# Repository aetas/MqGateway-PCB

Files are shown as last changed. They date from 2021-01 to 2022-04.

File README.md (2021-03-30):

# MqGateway PCB projects

Schematics and PCB design for MqGateway boards.

Source files can be read with [KiCad](https://kicad-pcb.org/). GERBER files are available in the [releases](https://github.com/aetas/MqGateway-PCB/releases).

Read more about MqGateway on the [documentation site](https://mqgateway.com).

## Issues

If you have found any problem with the PCB projects - please create an issue in [aetas/mqgateway repository](https://github.com/aetas/mqgateway).

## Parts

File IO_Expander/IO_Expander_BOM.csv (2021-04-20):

Quantity | Value | References | Package | Device | Description | Link
4 | Screw_Terminal_01x02 | 12V_OUTPUT_1, 5V_OUTPUT_1, EXT_BUTTON_1, POWER_SWITCH_1 |  |  | Screw Terminal 2-pin | https://www.piekarz.pl/00561-laczowka-xy306a-02p-5-0mm-2-tory/
1 | Power switch | POWER_SWITCH_1 |  | KCD1-110A | Sub-miniature Rocker Switch OFF-ON, power switch | https://en.maritex.com.pl/product/show/39905
1 | LED Red 3mm | 12V_POWER_LED_1 | d=3mm |  | Red LED d=3mm
1 |  | R_12V_POWER_LED_1 | THT |  | Red LED resistor
1 | LED Red 3mm | 5V_POWER_LED_1 | d=3mm |  | Red LED d=3mm
1 |  | R_5V_POWER_LED_1 | THT |  | Red LED resistor
1 | LED Blue 3mm | EXTENDER_CHECK_LED_1 | d=3mm |  | Blue LED d=3mm
1 |  | R_EXTENDER_CHECK_LED_1 | THT |  | Blue LED resistor
1 |  | DC_JACK_1 |  |  | DC Power Jack Plug Socket 2.1/5.5 | https://www.piekarz.pl/02542-gniazdo-zasilajace-dc-gdc21-55-2-1mm/
4 |  | EXPANDER_1, EXPANDER_2, EXPANDER_3, EXPANDER_4 | DIP28 | MCP23017-E/SP | MCP23017 expanders | https://www.piekarz.pl/22712-przetwornik-microchip-mcp23017-e-sp/
4 | 36x10mm | EXPANDER_1, EXPANDER_2, EXPANDER_3, EXPANDER_4 | DIP28p narrow (0.3'') |  | DIP28 sockets for MCP23017 expanders | https://www.piekarz.pl/04818-podstawka-zwykla-dip-dip28p-28-torow/
1 |  | LM2596_Module_1 |  | LM2596 module | LM2596 Step-Down module | https://www.aliexpress.com/item/4000627309533.html
1 | 8P8C x16 | RJ45x16_1 |  | RJ45 x16 | 8P8C/RJ45 Ethernet Socket 2x8 Ports | https://www.aliexpress.com/item/1212644854.html
1 |  | RS485_CONNECTOR_1 |  | PTR STL1550/4G-3.5-H | Terminal block 4-pins 3.5mm | https://www.piekarz.pl/00604-laczowka-stl1550-4-gh-4-tory/
1 | 2x2 | RS485_OUT_Jumpers_1 |  |  | Pin header 2x2 | https://www.piekarz.pl/35904-piny-wtyk-pld20s-20-torow/
2 | Jumper | RS485_OUT_Jumpers_1 |  |  | Jumper for pin header | https://www.piekarz.pl/00481-zwora-jumper-b-1-tor/
3 | Jumper | SW_SLIDE_SPDT_1, SW_SLIDE_SPDT_2, SW_SLIDE_SPDT_3 |  | KLS7-SS02-12F20 | Miniature SPDT Slide Switch ON-ON | https://www.piekarz.pl/33509-przelacznik-ss02-12f20-l-6/
2 |  | EXTRA_IO_CONNECTOR_1, EXTRA_IO_CONNECTOR_2 |  |  | IDC 10 pin male socket | https://www.piekarz.pl/17934-wtyk-bh10-s-10-torow/
2 | IDC10-CT | - |  |  | Female IDC-plug 10 pin for ribbon cable | https://www.piekarz.pl/02212-gniazdo-fc10-idc10-10-torow/
1 | 10-core ribbon | - |  |  | 10-core ribbon cable | https://www.piekarz.pl/06502-przewod-plaski-awg28-10-10-zyl-linka-cu-0-09mm2/

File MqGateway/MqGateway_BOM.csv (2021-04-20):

Quantity | Value | References | Package | Device | Description | Link
4 | 2x2 | 3V3_ADD_1, 5V_ADD_1, RS485_MAX_Jumpers_1, RS485_Jumpers_1 |  |  | Pin header 2x2 | https://www.piekarz.pl/35904-piny-wtyk-pld20s-20-torow/
1 | 1x2 | 5V_TO_DL33CV_JUMPER_1 |  |  | Pin header 1x2 | https://www.piekarz.pl/35901-piny-wtyk-pls02s-2-tory/
5 | Jumper | 3V3_ADD_1, 5V_ADD_1, RS485_MAX_Jumpers_1, RS485_Jumpers_1, 5V_TO_DL33CV_JUMPER_1 |  |  | Jumper for pin header | https://www.piekarz.pl/00481-zwora-jumper-b-1-tor/
1 | LD1117V33 | 3V3_REGULATOR_1 | TO-220-3 | LD1117V33 | Linear Voltage Regulator 3.3V | https://www.piekarz.pl/13101-stabilizator-st-microelectronics-ld1117v33c/
2 | SW_Push | BUTTON_1 BUTTON_2 |  | KLS7-TS6601 | Tact switch button 4-pin (6x6mm) | https://www.piekarz.pl/00678-mikroprzycisk-kls-ts6601-5-6x6mm-5mm-1-5mm/
2 | Screw_Terminal_01x02 | POWER_SWITCH_1, BUTTON_3 |  |  | Screw Terminal 2-pin | https://www.piekarz.pl/00561-laczowka-xy306a-02p-5-0mm-2-tory/
1 | DC 5V | DC_JACK_1 |  |  | DC Power Jack Plug Socket 2.1/5.5 | https://www.piekarz.pl/02542-gniazdo-zasilajace-dc-gdc21-55-2-1mm/
4 | MCP23017-E/SP | EXPANDER_1, EXPANDER_2, EXPANDER_3, EXPANDER_4 | DIP28 | MCP23017-E/SP | MCP23017 expanders | https://www.piekarz.pl/22712-przetwornik-microchip-mcp23017-e-sp/
4 | 36x10mm | EXPANDER_1, EXPANDER_2, EXPANDER_3, EXPANDER_4 | DIP28p narrow (0.3'') |  | DIP28 sockets for MCP23017 expanders | https://www.piekarz.pl/04818-podstawka-zwykla-dip-dip28p-28-torow/
1 | Extra IO Connector | EXTRA_IO_CONNECTOR_1 |  |  | Extra IO Connector, IDC 10 pin male socket | https://www.piekarz.pl/17934-wtyk-bh10-s-10-torow/
1 | LEVEL SHIFTER | LEVEL_SHIFTER_1 |  |  | Logic level converter 4-ch 5V to 3.3V | https://www.aliexpress.com/item/32715353192.html
1 | MAX485 | MAX485 |  |  | MAX485 TTL to RS-485 Interface Module | https://www.aliexpress.com/item/4000112077167.html
1 | 2x12 | NanoPi_NEO_1 |  |  | NanoPi NEO Socket, IDC 24 pin male socket | https://www.maritex.com.pl/zlacza/zlacza_idc/idc_w_rastrze_2_54mm/zlacza_kolkowe_proste_w_rastrze_2_54mm_conntherm_1/bh24s-ct.html
4 | M2.5 30mm | - |  | WKKM2530 | Screw M2.5 30mm for NanoPi NEO | https://www.piekarz.pl/21920-wkret-m2-5-wkkm2530/
4 | M2.5 | - |  | NOM252 | Screw Nut M2.5 for NanoPi NEO | https://www.piekarz.pl/09575-nakretka-m2-5-nom252/
2 | IDC24-CT | - |  | IDC24-CT | Female IDC-plug 24 pin for ribbon cable | https://en.maritex.com.pl/connectors/idc_connectors/idc_connectors_2_54mm_pitch/idc_female_sockets_for_ribbon_cable_2_54_mm_pitch_conntherm/idc24-ct.html
1 | 15cm 24-core ribbon | - |  |  | 24-core ribbon cable (15cm) | https://www.aliexpress.com/item/32824377459.html
1 | LED Red 3mm | POWER_LED_1 | THT d=3mm |  | Red LED d=3mm
1 | 150 | R_LED_POWER_1 | THT |  | Red LED resistor
1 | 8P8C x16 | RJ45x16_1 |  |  | 8P8C/RJ45 Ethernet Socket 2x8 Ports | https://www.aliexpress.com/item/1212644854.html
1 | LED Yellow Green 3mm | STATUS_RGB_LED_1 | THT d=3mm | HL-309S40YU77GC-C | 2-color Yellow and Green LED d=3mm | https://en.maritex.com.pl/clearance_sale/led/led_-_diodes/ledb-3ygw30-c3.html
1 | 10 | R_LED1 | THT |  | Green LED Resistor
1 | 43 | R_LED2 | THT |  | Yellow LED Resistor
1 | Power switch | - |  | KCD1-110A | Sub-miniature Rocker Switch OFF-ON, power switch | https://en.maritex.com.pl/product/show/39905
1 | Push button | - |  | PBW-12B | 12mm diameter monostable switch OFF-(ON) | https://www.piekarz.pl/34283-przelacznik-pbw-12b/

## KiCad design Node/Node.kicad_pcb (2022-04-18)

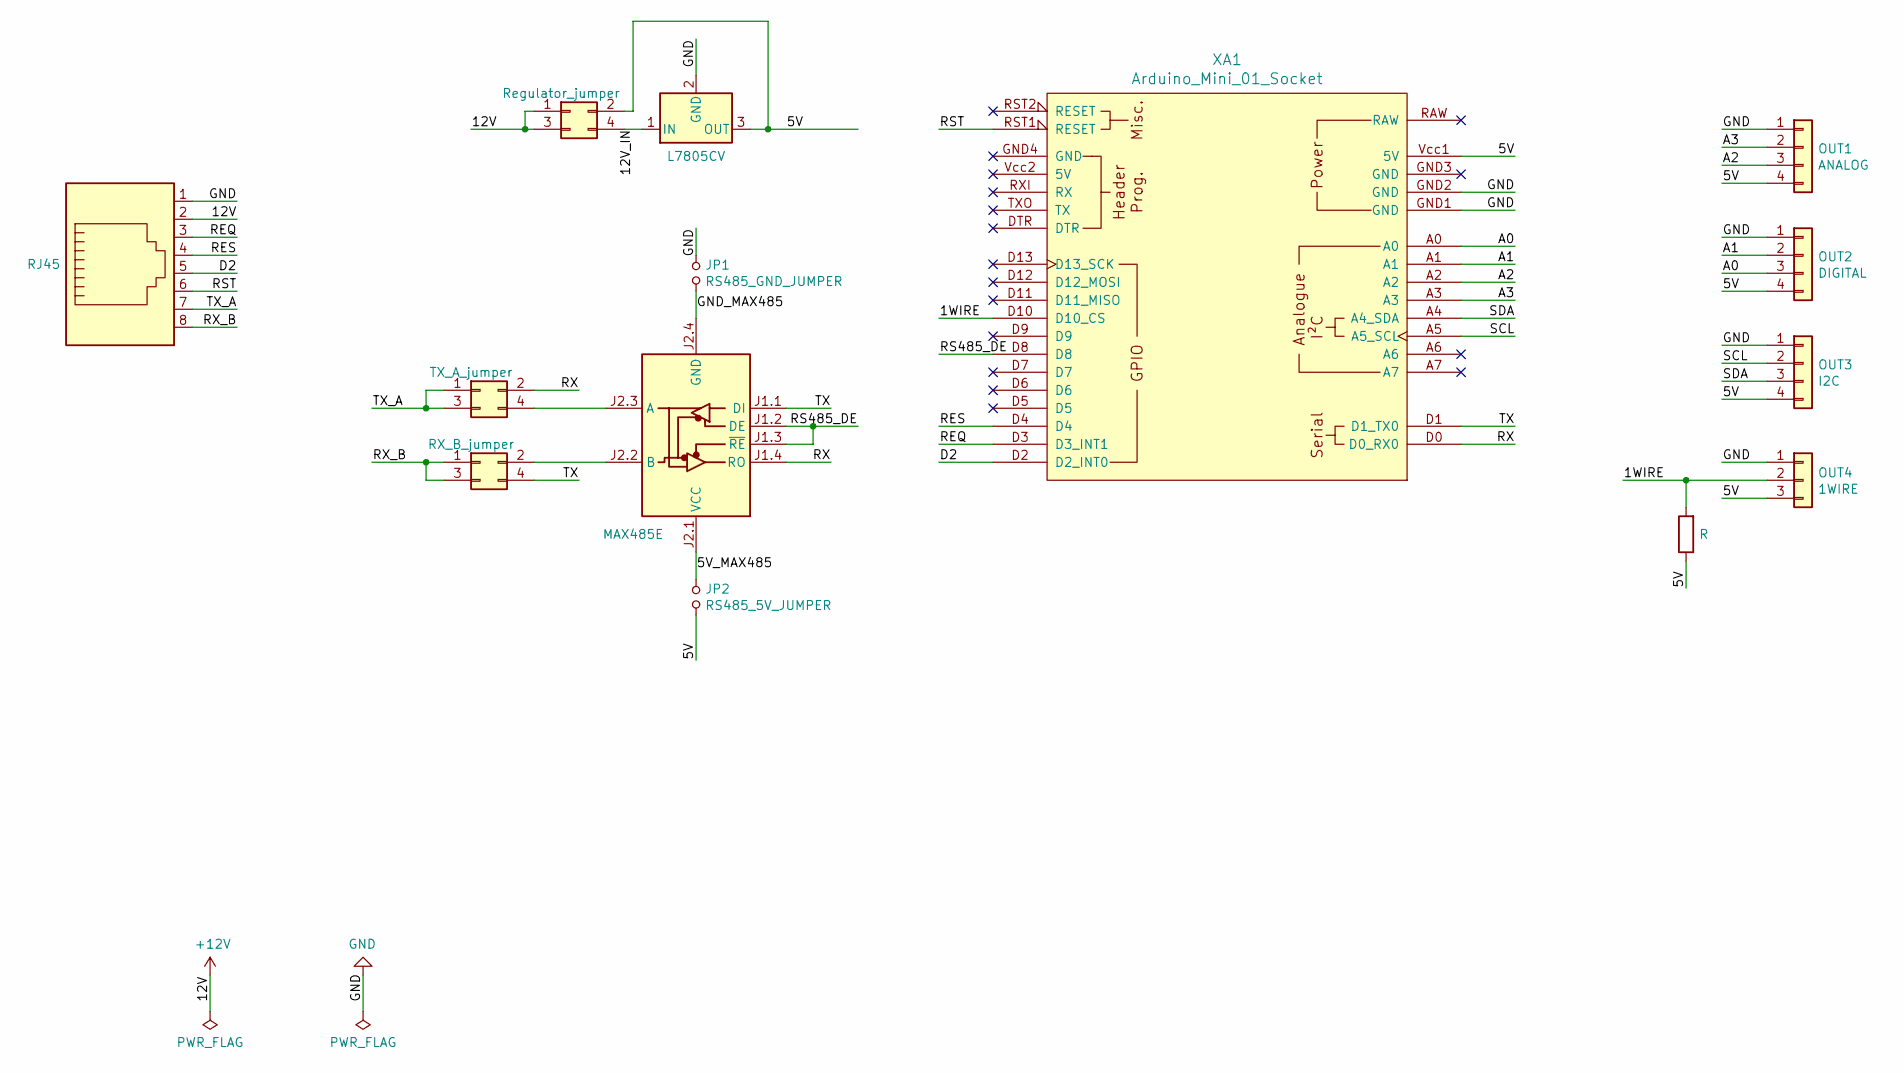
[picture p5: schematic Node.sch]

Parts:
J1: Regulator_jumper; pin_strip_2x2
J2: RX_B_jumper; pin_strip_2x2
J3: TX_A_jumper; pin_strip_2x2
J4: RJ45; RJ45_Amphenol_54602-x08_Horizontal
JP1: RS485_GND_JUMPER; pin_strip_2
JP2: RS485_5V_JUMPER; pin_strip_2
OUT1: ANALOG; Molex_PicoBlade_53047-0410_1x04_P1.25mm_Vertical
OUT2: DIGITAL; Molex_PicoBlade_53047-0410_1x04_P1.25mm_Vertical
OUT3: I2C; Molex_PicoBlade_53047-0410_1x04_P1.25mm_Vertical
OUT4: 1WIRE; Molex_PicoBlade_53047-0310_1x03_P1.25mm_Vertical
R1: R; R_Axial_DIN0204_L3.6mm_D1.6mm_P7.62mm_Horizontal
U1: MAX485E; RS485-TTL-CONVERTER
U2: L7805CV; TO-220-3_Vertical
XA1: Arduino_Mini_01_Socket; Arduino_Pro_Mini_Clone_Socket

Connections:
+12V: J1.1, J1.3, J4.2
/1WIRE: OUT4.2, R1.2, XA1.D10 (D10_CS)
/5V: J1.2, JP2.1, OUT1.4, OUT2.4, OUT3.4, OUT4.3, R1.1, U2.3 (OUT), XA1.Vcc1 (5V)
/5V_MAX485: JP2.2, U1.J2.1 (VCC)
/12V_IN: J1.4, U2.1 (IN)
/A0: OUT2.3, XA1.A0
/A1: OUT2.2, XA1.A1
/A2: OUT1.3, XA1.A2
/A3: OUT1.2, XA1.A3
/D2: J4.5, XA1.D2 (D2_INT0)
/GND_MAX485: JP1.1, U1.J2.4 (GND)
/REQ: J4.3, XA1.D3 (D3_INT1)
/RES: J4.4, XA1.D4
/RS485_DE: U1.J1.2 (DE), U1.J1.3 (~RE), XA1.D8
/RST: J4.6, XA1.RST1 (RESET)
/RX: J3.2, U1.J1.4 (RO), XA1.D0 (D0_RX0)
/RX_B: J2.1, J2.3, J4.8
/SCL: OUT3.2, XA1.A5 (A5_SCL)
/SDA: OUT3.3, XA1.A4 (A4_SDA)
/TX: J2.4, U1.J1.1 (DI), XA1.D1 (D1_TX0)
/TX_A: J3.1, J3.3, J4.7
GND: J4.1, JP1.2, OUT1.1, OUT2.1, OUT3.1, OUT4.1, U2.2 (GND), XA1.GND1 (GND), XA1.GND2 (GND)
unnamed: J2.2, U1.J2.2 (B)
unnamed: J3.4, U1.J2.3 (A)

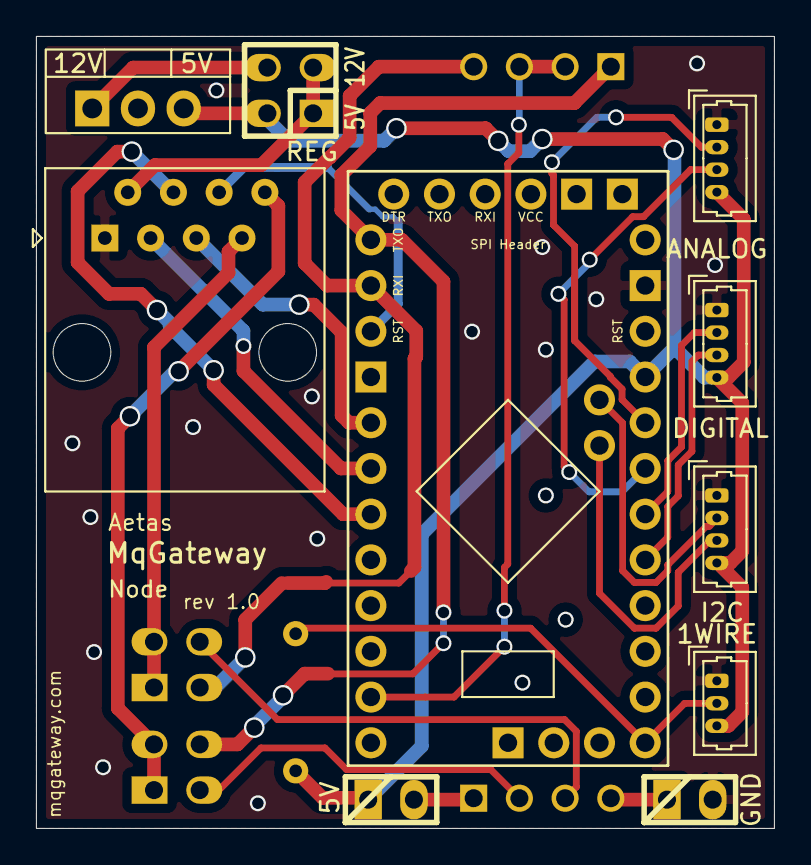
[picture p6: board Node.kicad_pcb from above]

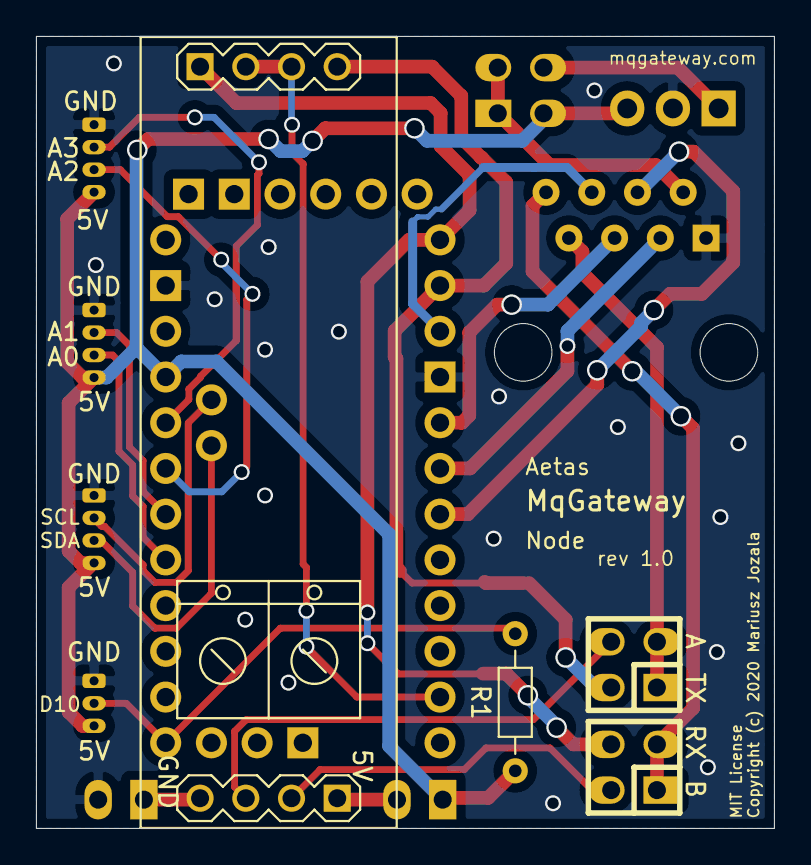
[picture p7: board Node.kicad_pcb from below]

Board: 2 copper layers, 41.0 x 44.0 mm, 14 parts (4 on the bottom side), 24 nets.

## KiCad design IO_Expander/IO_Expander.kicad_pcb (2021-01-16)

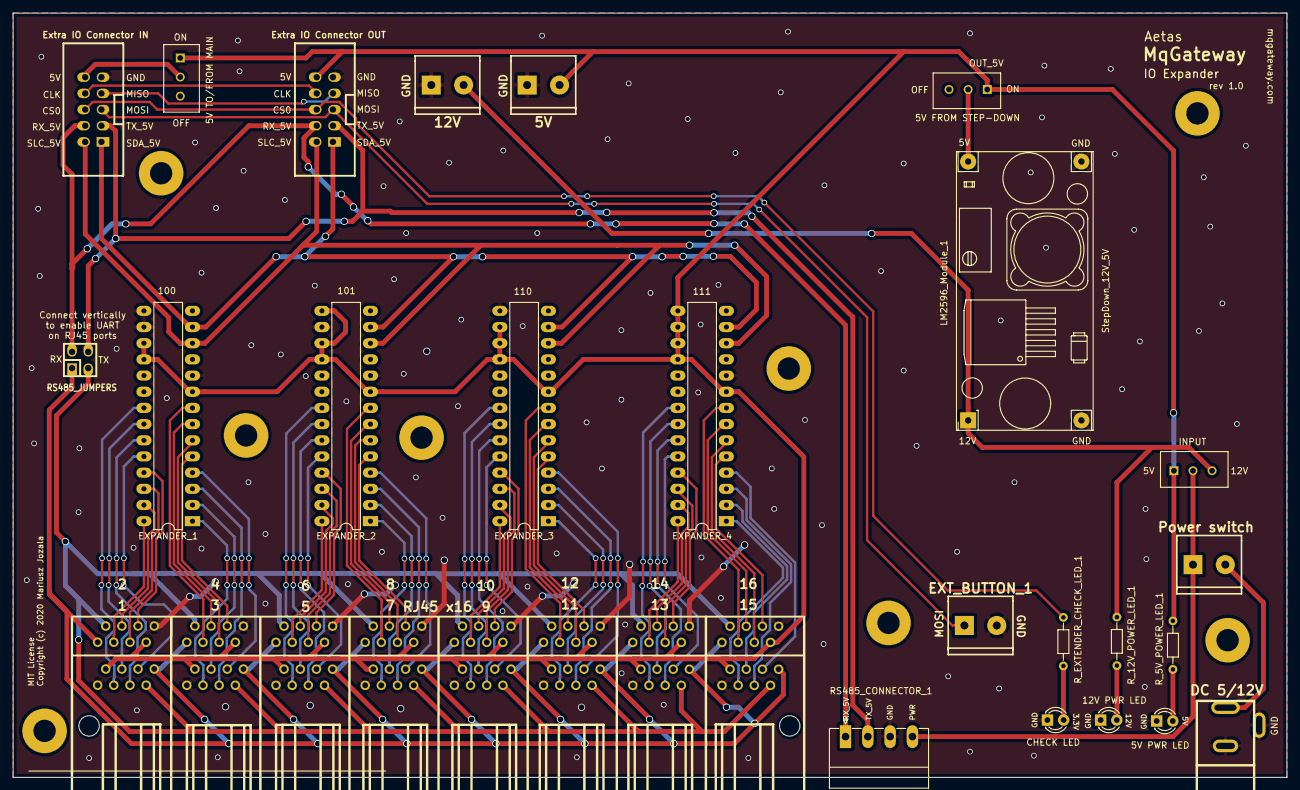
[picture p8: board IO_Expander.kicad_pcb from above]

Board: 2 copper layers, 200.0 x 120.0 mm, 24 parts (0 on the bottom side), 84 nets.

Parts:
5V_OUTPUT_1: 5V; mors_2p
5V_POWER_LED_1: 5V PWR LED; LED_D3.0mm
12V_OUTPUT_1: 12V; mors_2p
12V_POWER_LED_1: 12V PWR LED; LED_D3.0mm
DC_JACK_1: DC 5/12V; dc_socket
EXPANDER_1, EXPANDER_2, EXPANDER_3, EXPANDER_4: MCP23017_SP; DIP-28_W7.62mm_LongPads
EXTENDER_CHECK_LED_1: CHECK LED; LED_D3.0mm
EXTRA_IO_CONNECTOR_1: Extra IO Connector IN; vasch_strip_5x2
EXTRA_IO_CONNECTOR_2: Extra IO Connector OUT; vasch_strip_5x2
EXT_BUTTON_1: Screw_Terminal_01x02; mors_2p
LM2596_Module_1: StepDown_12V_5V; YAAJ_DCDC_StepDown_LM2596
POWER_SWITCH_1: Power switch; mors_2p
RJ45x16_1: RJ45 x16; 8p8c_2x8_roomhub
RS485_CONNECTOR_1: RS485 Connector; PhoenixContact_MC-G_04x3.50mm_Angled
RS485_OUT_Jumpers_1: RS485_JUMPERS; pin_strip_2x2
R_5V_POWER_LED_1, R_12V_POWER_LED_1: R_POWER_LED; R_Axial_DIN0204_L3.6mm_D1.6mm_P7.62mm_Horizontal
R_EXTENDER_CHECK_LED_1: R_EXTENDER_CHECK_LED; R_Axial_DIN0204_L3.6mm_D1.6mm_P7.62mm_Horizontal
SW_SLIDE_SPDT_1: SW_EXTRA_5V_ONOFF; SW_SPDT-3mm
SW_SLIDE_SPDT_2: SW_5V_OR_12V; SW_SPDT-3mm
SW_SLIDE_SPDT_3: 5V FROM STEP-DOWN; SW_SPDT-3mm

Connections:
+5V: 5V_OUTPUT_1.2, EXPANDER_1.9, EXPANDER_1.17, EXPANDER_1.18, EXPANDER_2.9, EXPANDER_2.15, EXPANDER_2.17, EXPANDER_2.18, EXPANDER_3.9, EXPANDER_3.16, EXPANDER_3.17, EXPANDER_3.18, EXPANDER_4.9, EXPANDER_4.15, EXPANDER_4.16, EXPANDER_4.17, EXPANDER_4.18, EXTRA_IO_CONNECTOR_2.10, RJ45x16_1.1.2, RJ45x16_1.2.2, RJ45x16_1.3.2, RJ45x16_1.4.2, RJ45x16_1.5.2, RJ45x16_1.6.2, RJ45x16_1.7.2, RJ45x16_1.8.2, RJ45x16_1.9.2, RJ45x16_1.10.2, RJ45x16_1.11.2, RJ45x16_1.12.2, RJ45x16_1.13.2, RJ45x16_1.14.2, RJ45x16_1.15.2, RJ45x16_1.16.2, R_5V_POWER_LED_1.2, SW_SLIDE_SPDT_1.1, SW_SLIDE_SPDT_2.1, SW_SLIDE_SPDT_3.1
+12V: 12V_OUTPUT_1.2, LM2596_Module_1.1, R_12V_POWER_LED_1.2, SW_SLIDE_SPDT_2.3
/CLK0: EXTRA_IO_CONNECTOR_1.8, EXTRA_IO_CONNECTOR_2.8
/CS0: EXTRA_IO_CONNECTOR_1.6, EXTRA_IO_CONNECTOR_2.6, R_EXTENDER_CHECK_LED_1.2
/MISO0: EXTRA_IO_CONNECTOR_1.7, EXTRA_IO_CONNECTOR_2.7
/MOSI0: EXTRA_IO_CONNECTOR_1.5, EXTRA_IO_CONNECTOR_2.5, EXT_BUTTON_1.1
/POWER: POWER_SWITCH_1.1, RS485_CONNECTOR_1.4, SW_SLIDE_SPDT_2.2
/POWER_START: DC_JACK_1.3, POWER_SWITCH_1.2
/RX1_5V: EXTRA_IO_CONNECTOR_1.4, EXTRA_IO_CONNECTOR_2.4, RS485_CONNECTOR_1.1, RS485_OUT_Jumpers_1.2
/RX1_OUT: RJ45x16_1.1.8, RJ45x16_1.2.8, RJ45x16_1.3.8, RJ45x16_1.4.8, RJ45x16_1.5.8, RJ45x16_1.6.8, RJ45x16_1.7.8, RJ45x16_1.8.8, RJ45x16_1.9.8, RJ45x16_1.10.8, RJ45x16_1.11.8, RJ45x16_1.12.8, RJ45x16_1.13.8, RJ45x16_1.14.8, RJ45x16_1.15.8, RJ45x16_1.16.8, RS485_OUT_Jumpers_1.1
/SCL1_HV: EXPANDER_1.12, EXPANDER_2.12, EXPANDER_3.12, EXPANDER_4.12, EXTRA_IO_CONNECTOR_1.2, EXTRA_IO_CONNECTOR_2.2
/SDA1_HV: EXPANDER_1.13, EXPANDER_2.13, EXPANDER_3.13, EXPANDER_4.13, EXTRA_IO_CONNECTOR_1.1, EXTRA_IO_CONNECTOR_2.1
/TX1_5V: EXTRA_IO_CONNECTOR_1.3, EXTRA_IO_CONNECTOR_2.3, RS485_CONNECTOR_1.2, RS485_OUT_Jumpers_1.4
/TX1_OUT: RJ45x16_1.1.7, RJ45x16_1.2.7, RJ45x16_1.3.7, RJ45x16_1.4.7, RJ45x16_1.5.7, RJ45x16_1.6.7, RJ45x16_1.7.7, RJ45x16_1.8.7, RJ45x16_1.9.7, RJ45x16_1.10.7, RJ45x16_1.11.7, RJ45x16_1.12.7, RJ45x16_1.13.7, RJ45x16_1.14.7, RJ45x16_1.15.7, RJ45x16_1.16.7, RS485_OUT_Jumpers_1.3
GND: 5V_OUTPUT_1.1, 5V_POWER_LED_1.1, 12V_OUTPUT_1.1, 12V_POWER_LED_1.1, DC_JACK_1.1, DC_JACK_1.2, EXPANDER_1.10, EXPANDER_1.15, EXPANDER_1.16, EXPANDER_2.10, EXPANDER_2.16, EXPANDER_3.10, EXPANDER_3.15, EXPANDER_4.10, EXTENDER_CHECK_LED_1.1, EXTRA_IO_CONNECTOR_1.9, EXTRA_IO_CONNECTOR_2.9, EXT_BUTTON_1.2, LM2596_Module_1.2, LM2596_Module_1.3, RJ45x16_1.1.1, RJ45x16_1.2.1, RJ45x16_1.3.1, RJ45x16_1.4.1, RJ45x16_1.5.1, RJ45x16_1.6.1, RJ45x16_1.7.1, RJ45x16_1.8.1, RJ45x16_1.9.1, RJ45x16_1.10.1, RJ45x16_1.11.1, RJ45x16_1.12.1, RJ45x16_1.13.1, RJ45x16_1.14.1, RJ45x16_1.15.1, RJ45x16_1.16.1, RS485_CONNECTOR_1.3
unnamed: 5V_POWER_LED_1.2, R_5V_POWER_LED_1.1
unnamed: 12V_POWER_LED_1.2, R_12V_POWER_LED_1.1
unnamed: EXPANDER_1.1, RJ45x16_1.3.3
unnamed: EXPANDER_1.2, RJ45x16_1.3.4
unnamed: EXPANDER_1.3, RJ45x16_1.3.5
unnamed: EXPANDER_1.4, RJ45x16_1.3.6
unnamed: EXPANDER_1.5, RJ45x16_1.4.3
unnamed: EXPANDER_1.6, RJ45x16_1.4.4
unnamed: EXPANDER_1.7, RJ45x16_1.4.5
unnamed: EXPANDER_1.8, RJ45x16_1.4.6
unnamed: EXPANDER_1.21, RJ45x16_1.1.3
unnamed: EXPANDER_1.22, RJ45x16_1.1.4
unnamed: EXPANDER_1.23, RJ45x16_1.1.5
unnamed: EXPANDER_1.24, RJ45x16_1.1.6
unnamed: EXPANDER_1.25, RJ45x16_1.2.3
unnamed: EXPANDER_1.26, RJ45x16_1.2.4
unnamed: EXPANDER_1.27, RJ45x16_1.2.5
unnamed: EXPANDER_1.28, RJ45x16_1.2.6
unnamed: EXPANDER_2.1, RJ45x16_1.7.3
unnamed: EXPANDER_2.2, RJ45x16_1.7.4
unnamed: EXPANDER_2.3, RJ45x16_1.7.5
unnamed: EXPANDER_2.4, RJ45x16_1.7.6
unnamed: EXPANDER_2.5, RJ45x16_1.8.3
unnamed: EXPANDER_2.6, RJ45x16_1.8.4
unnamed: EXPANDER_2.7, RJ45x16_1.8.5
unnamed: EXPANDER_2.8, RJ45x16_1.8.6
unnamed: EXPANDER_2.21, RJ45x16_1.5.3
unnamed: EXPANDER_2.22, RJ45x16_1.5.4
unnamed: EXPANDER_2.23, RJ45x16_1.5.5
unnamed: EXPANDER_2.24, RJ45x16_1.5.6
unnamed: EXPANDER_2.25, RJ45x16_1.6.3
unnamed: EXPANDER_2.26, RJ45x16_1.6.4
unnamed: EXPANDER_2.27, RJ45x16_1.6.5
unnamed: EXPANDER_2.28, RJ45x16_1.6.6
unnamed: EXPANDER_3.1, RJ45x16_1.11.3
unnamed: EXPANDER_3.2, RJ45x16_1.11.4
unnamed: EXPANDER_3.3, RJ45x16_1.11.5
unnamed: EXPANDER_3.4, RJ45x16_1.11.6
unnamed: EXPANDER_3.5, RJ45x16_1.12.3
unnamed: EXPANDER_3.6, RJ45x16_1.12.4
unnamed: EXPANDER_3.7, RJ45x16_1.12.5
unnamed: EXPANDER_3.8, RJ45x16_1.12.6
unnamed: EXPANDER_3.21, RJ45x16_1.9.3
unnamed: EXPANDER_3.22, RJ45x16_1.9.4
unnamed: EXPANDER_3.23, RJ45x16_1.9.5
unnamed: EXPANDER_3.24, RJ45x16_1.9.6
unnamed: EXPANDER_3.25, RJ45x16_1.10.3
unnamed: EXPANDER_3.26, RJ45x16_1.10.4
unnamed: EXPANDER_3.27, RJ45x16_1.10.5
unnamed: EXPANDER_3.28, RJ45x16_1.10.6
unnamed: EXPANDER_4.1, RJ45x16_1.15.3
unnamed: EXPANDER_4.2, RJ45x16_1.15.4
unnamed: EXPANDER_4.3, RJ45x16_1.15.5
unnamed: EXPANDER_4.4, RJ45x16_1.15.6
unnamed: EXPANDER_4.5, RJ45x16_1.16.3
unnamed: EXPANDER_4.6, RJ45x16_1.16.4
unnamed: EXPANDER_4.7, RJ45x16_1.16.5
unnamed: EXPANDER_4.8, RJ45x16_1.16.6
unnamed: EXPANDER_4.21, RJ45x16_1.13.3
unnamed: EXPANDER_4.22, RJ45x16_1.13.4
unnamed: EXPANDER_4.23, RJ45x16_1.13.5
unnamed: EXPANDER_4.24, RJ45x16_1.13.6
unnamed: EXPANDER_4.25, RJ45x16_1.14.3
unnamed: EXPANDER_4.26, RJ45x16_1.14.4
unnamed: EXPANDER_4.27, RJ45x16_1.14.5
unnamed: EXPANDER_4.28, RJ45x16_1.14.6
unnamed: EXTENDER_CHECK_LED_1.2, R_EXTENDER_CHECK_LED_1.1
unnamed: EXTRA_IO_CONNECTOR_1.10, SW_SLIDE_SPDT_1.2
unnamed: LM2596_Module_1.4, SW_SLIDE_SPDT_3.2

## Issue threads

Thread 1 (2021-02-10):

I/O Expander Board - release date

galciu, 2021-02-10:
Dear Mariusz,

on the site it says WIP
https://mqgateway.com/hardware/io-expander-board/

but on GIT there are files for expander, are this files ready?
Can I use them?

PS
Project looks awesome! :)

jozala, 2021-02-10:
Hi @galciu,
I have the prototype of I/O Expander board ready and single board working at my home for two weeks now. It seems to be working fine, but I still consider it as a test phase :) .
For main boards - I have five of them running for 4 months without any problems so I consider them stable.

I am happy you've found the project and like it :) . I still haven't publicly announced the project anywhere because I am working on the proper casing.

Just out of curiosity - can you tell me how have you found it?

Mariusz

galciu, 2021-02-12:
Dear Mariusz,

previous version Hub Room was posted on OpenHab forum.
I was going to design similar solution, and luckily We've found Your
project.
I'll be glad to test this prototype, so this file on github we can use to
print?

Pozdrawiam
Bartosz Gala
+48 501 737 737

Pomyśl o środowisku naturalnym zanim wydrukujesz ten email / Please
consider the environment before printing this e-mail.

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

jozala, 2021-02-12:
The files on GitHub are the latest ones and this is what I am running on myself.
Let me know if you have any questions or feedback of any kind.

galciu, 2021-02-12:
Thank You 😎👩‍💻

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

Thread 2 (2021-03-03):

BOM

galciu, 2021-03-03:
Dear Mariusz,
do You have more precise BOM than this one:

https://mqgateway.com/hardware/components/
?
So it'll be easier to search for exact components that You used.

Like first position:

this one:
https://pl.farnell.com/wurth-elektronik/694106301002/connector-power-entry-jack-3a/dp/2472149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|pcrid|491302916621|plid||kword||match||slid||product|2472149|pgrid|115905809683|ptaid|pla-892249581016|&CMP=KNC-GPL-GEN-SHOPPING-Connectors-DoublePresence_13_01_2021

or this one:
https://pl.farnell.com/schurter/4840-2201/dc-power-jack-2p-2a-12v-pcb/dp/3282173?mckv=sb0HyffmN_dc|pcrid|491302916621|plid||kword||match||slid||product|3282173|pgrid|115905809683|ptaid|pla-637698714168|&CMP=KNC-GPL-GEN-SHOPPING-Connectors-DoublePresence_13_01_2021

jozala, 2021-03-03:
That's a good point. I will try to add this information to the documentation.
For now I will try to give you the links I have for the main board. If you have problem with some specific element - let me know.

[DC Power Jack Plug Socket 2.1/5.5](https://www.piekarz.pl/02542-gniazdo-zasilajace-dc-gdc21-55-2-1mm/)
[MCP23017](https://uk.farnell.com/microchip/mcp23017-e-sp/ic-io-expander-16bit-i2c-28dip/dp/1332088)
[Screw Terminal 2-pin](https://en.maritex.com.pl/product/show/44163)
[RJ45 Ethernet Socket 2x8 Ports](https://aliexpress.com/item/1212644854.html)
[Micro switch button 4-pin](https://www.piekarz.pl/00678-mikroprzycisk-kls-ts6601-5-6x6mm-5mm-1-5mm/)
[Logic level converter 4-ch 5V to 3.3V](https://aliexpress.com/item/32715353192.html)
[IDC10 Male Pin PCB Socket](https://www.piekarz.pl/17934-wtyk-bh10-s-10-torow/)
[LD1117V33 Linear Voltage Regulator 3.3V](https://aliexpress.com/item/32281417292.html)
[Power switch button](https://en.maritex.com.pl/product/show/39905)
[Case switch button](https://www.piekarz.pl/34283-przelacznik-pbw-12b/)

galciu, 2021-03-03:
Awesome! :)
Thank You.

galciu, 2021-03-03:
Tell me please, did You use some specific case?

jozala, 2021-03-03:
I will add more information about the casing soon. For now I can tell you I have prepared rack case for the MqGateway + I/O Expander combo. It uses standard rack case from [this store](https://www.piekarz.pl/30056-obudowa-zp-sesmil-1u-2013-205/).
I've send the fronts to be cut out by professionals and the results looks like [this](https://mqgateway.com/user-guide/images/cased-mqgateway-with-io-expander-small.jpg).

I need to correct a CAD files for front cutting a bit and I am going to publish everything.

galciu, 2021-03-05:
Please confirm those:

MAX485 module:
https://allegro.pl/oferta/uklad-max485-dip-8-interfejs-rs485-9413374993

DIP28 Socket
https://allegro.pl/oferta/podstawka-dip28-precyzyjna-0-6-komplet-5-sztuk-6119161501

Pozdrawiam
Bartosz Gala
+48 501 737 737

Pomyśl o środowisku naturalnym zanim wydrukujesz ten email / Please
consider the environment before printing this e-mail.

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

jozala, 2021-03-06:
MAX485 module:
https://allegro.pl/oferta/modul-konwerter-uart-ttl-rs485-max485-5v-arduino-5679704516

DIP28 Socket is for MCP23017. It should be narrow and NOT precise.
https://www.piekarz.pl/04818-podstawka-zwykla-dip-dip28p-28-torow/

Please keep in mind that MAX485 module is optional. I am currently not using it. Instead I use UART TTL communication directly. I haven't done extensive tests, but it works fine for me with 3 devices connected with up to 10 meters cable. For longer distances it would probably need MAX485.
Currently MqGateway doesn't work with the actual RS485 bus (but hardware is prepared for that on expander board). Instead it allows to connect devices which communicate with UART or RS485 to be able to receive data from them (like temperature from Arduino+BME280). I hope I will find some time soon to describe it better in documentation. For now, if RS485 communication is important for you and you have any questions - please ask.

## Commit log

2021-01-16 Publishing boards
    [IO_Expander.kicad_pcb, IO_Expander.sch, MqGateway.kicad_pcb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]
2021-04-20 BOM files added for MqGateway mainboard and I/O Expander Board
    [IO_Expander_BOM.csv, MqGateway_BOM.csv]
2022-02-23 Photos and renders of MqGateway boards added
2022-04-18 MqGateway Node v1 added
    [Node-B_Cu.gbr, Node-B_Mask.gbr, Node-B_Paste.gbr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]

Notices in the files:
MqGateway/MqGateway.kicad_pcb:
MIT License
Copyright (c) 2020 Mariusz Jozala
